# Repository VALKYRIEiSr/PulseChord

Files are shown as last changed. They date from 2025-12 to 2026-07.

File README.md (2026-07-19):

# PulseChord: Wearable Haptic/Vibrational Audio System
**OSHWA Certified Open Source Hardware | PK000001**
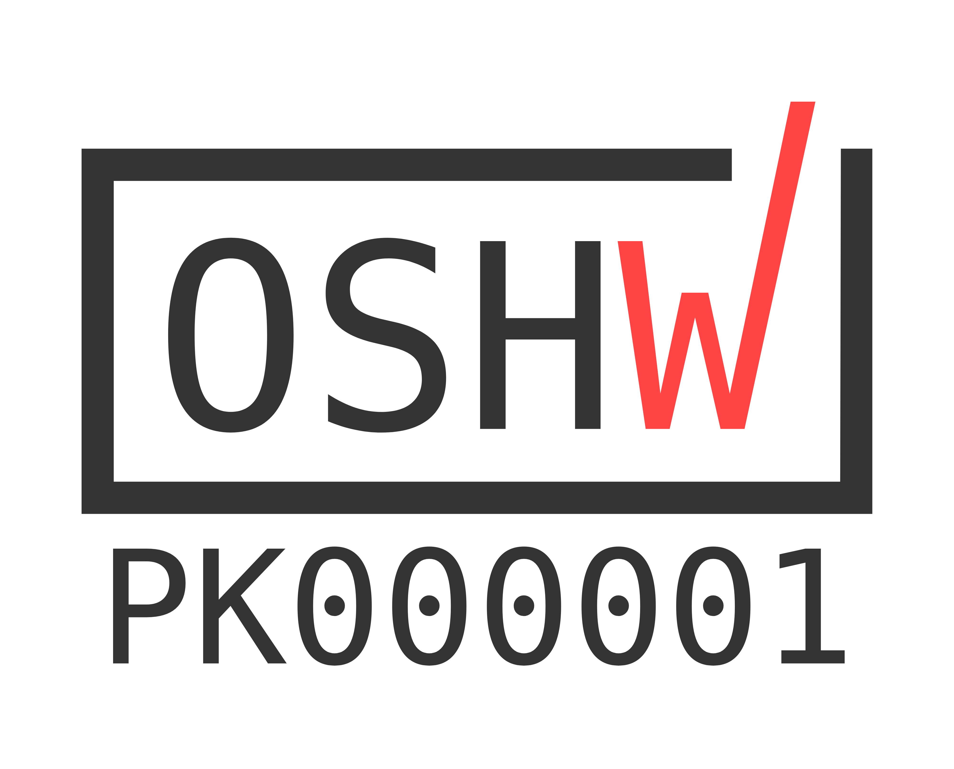
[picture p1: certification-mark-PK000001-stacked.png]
OSHWA Certification

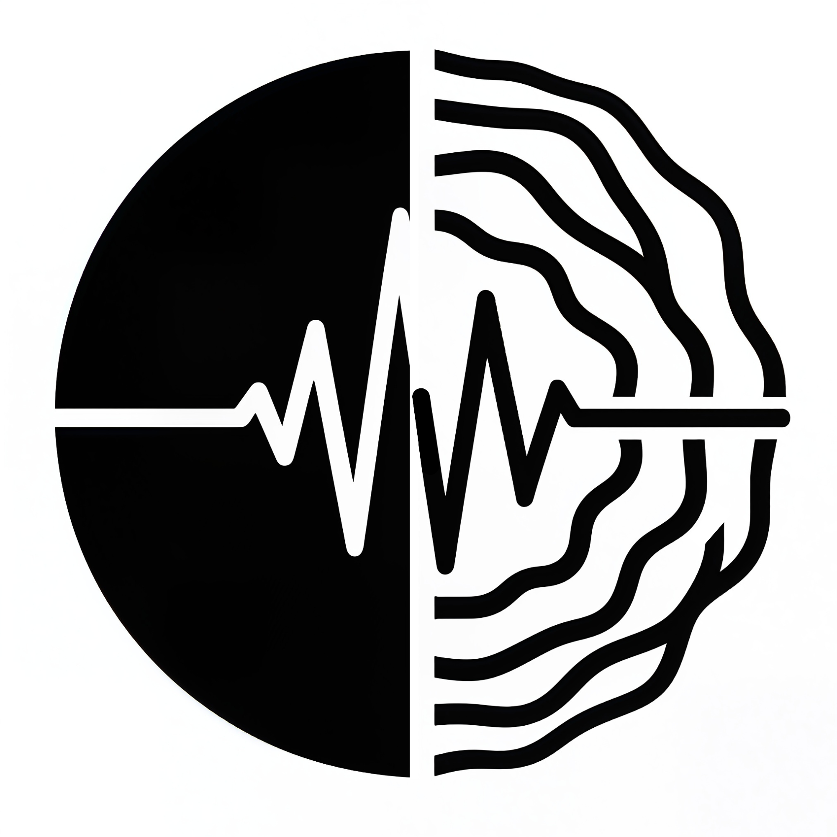
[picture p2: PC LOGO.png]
PulseChord Logo


## Project Overview
PulseChord is a purely analog haptic feedback belt that converts live audio into tactile vibrations through voice coil actuators positioned around the torso/waist. Designed to create an immersive sensory experience, it delivers real-time feedback corresponding to musical rhythm and dynamics.

This project bridges the gap between digital audio and physical sensation, utilizing an industrial manufacturing substrate to create an accessible, wearable haptic interface.

## Press & Recognition
PulseChord was featured as Pakistan's first OSHWA-certified project in the January 2026 Open Source Hardware Certification roundup:
* **Make: Magazine** — [Open Source Hardware Certifications for January 2026](https://makezine.com/article/technology/open-source/open-source-hardware-certifications-for-january-2026/)
* **Hackster.io** — [January 2026 Open Source Hardware Certification Roundup](https://www.hackster.io/news/january-2026-open-source-hardware-certification-roundup-2705cc24ead9)

## Technical Research
The academic theory and signal-conditioning research behind this project can be found on SSRN:
* **SSRN Research Paper:** [PulseChord: Wearable Haptic Systems](https://papers.ssrn.com/sol3/papers.cfm?abstract_id=5532803) (Please refer to for more details)

## Technical Specifications
* **Architecture:** Purely Analog Signal Processing (No Software/Microcontroller)
* **Haptic Drivers:** 6x Full-range vibrational voice coil actuators (4Ω, 5W)
* **Amplification:** Dual TPA3110 (XHA232) Class D Stereo Amplifiers
* **Wiring Configuration:** Drivers are wired in **series pairs** (8Ω per pair) as shown in `Schematic 2.png`.
* **Conditioning:** TL074-based low-noise quad op-amp stage
* **Power:** 11.1V 3S LiPo Battery (2200mAh)
* **Chassis:** 50mm High-durability Nylon webbing with 3D-printed modular mounts
* **Fasteners:** M2 x 30mm Stainless Steel hardware

## Repository Structure
* `Hardware`: Eagle Schematic (`.sch`) and Board (`.brd`) files
* `Mechanical`: 3D source files (`.stl`, `.FCStd`) for speaker holders
* `BOM.txt`: Formatted Bill of Materials with manufacturer specifications
* `BOM.xlxs`: Formatted Bill of Materials with costs
* `LICENSE.txt`: Hardware (CERN-OHL-P-2.0) and Documentation (CC-BY-SA-4.0) licenses
* `GerberFiles.zip`: Production-ready files for PCB fabrication

## Assembly Quick-Start
1. **PCB:** Fabricate the Gerber files using a standard 2-layer FR4 process.
2. **Printing:** Print 6x `Holder Design-Body.stl` in PLA (20% infill).
3. **Mechanical Assembly:** First, mount the speakers into the 3D-printed holders using M2 x 30mm screws and nuts, as detailed in **Speaker.png**.
    * Once secured, thread the 50mm nylon strap through the integrated slots in the holders.
    * Finally, glue, staple, or stitch the velcro hook to one end and the velco loop to the other.
4. **Wiring:** Wire the speakers in series pairs as detailed in **Schematic 2.png**. Connect each 8Ω load to the amplifier output channels.

## Licensing
* **Hardware:** [CERN-OHL-P-2.0](https://spdx.org/licenses/CERN-OHL-P-2.0.html)
* **Documentation:** [CC-BY-SA-4.0](https://creativecommons.org/licenses/by-sa/4.0/)

---
**Developer:** Hariz Zoran Farooq
**Contact:** harizzoranfarooq@gmail.com
*Certified with the Open Source Hardware Association | PK000001.*

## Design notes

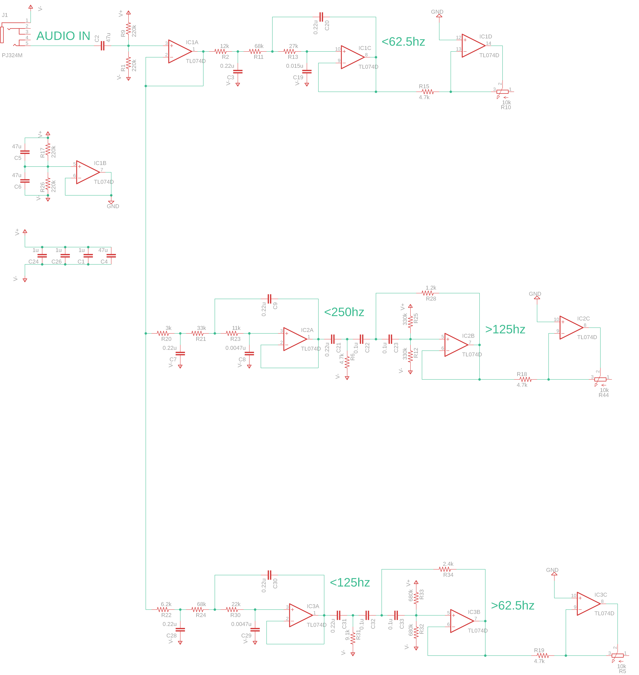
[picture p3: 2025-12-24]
Schematic.png

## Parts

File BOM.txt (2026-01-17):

================================================================================
                       BILL OF MATERIALS: PULSECHORD
================================================================================
Project Status: OSHWA-Compliant Documentation
License:        CERN-OHL-P (Hardware), CC-BY-SA (Documentation)

1. SURFACE MOUNT DEVICES (PCB COMPONENTS)
--------------------------------------------------------------------------------
PART            VALUE       PACKAGE         DESCRIPTION
--------------------------------------------------------------------------------
C1, C24, C26    1u          C0603           Ceramic Capacitor
C2, C4-C6       47u         C0603           Ceramic Capacitor (Bulk)
C3, C7, C9      0.22u       C0603           Ceramic Capacitor
C20, C21        0.22u       C0603           Ceramic Capacitor
C28, C30, C31   0.22u       C0603           Ceramic Capacitor
C8, C29         0.0047u     C0603           Ceramic Capacitor
C19             0.015u      C0603           Ceramic Capacitor
C22, C23        0.1u        C0603           Ceramic Capacitor (Bypass)
C32, C33        0.1u        C0603           Ceramic Capacitor (Bypass)
IC1-IC3         TL074C      SO14            Low-Noise Quad Op-Amp
J1              PJ324M      PJ324M          3.5mm Stereo Audio Jack
R1, R9, R17     220k        R0603           Resistor
R26             220k        R0603           Resistor
R2              12k         R0603           Resistor
R5, R10, R44    10k         3RP/1610N       Potentiometer (Linear)
R6, R15, R18    4.7k        R0603           Resistor
R19             4.7k        R0603           Resistor
R11, R24        68k         R0603           Resistor
R12, R25        330k        R0603           Resistor
R13             27k         R0603           Resistor
R20             3k          R0603           Resistor
R21             33k         R0603           Resistor
R22             6.2k        R0603           Resistor
R23             11k         R0603           Resistor
R28             1.2k        R0603           Resistor
R30             22k         R0603           Resistor
R31             9.1k        R0603           Resistor
R32, R33        680k        R0603           Resistor
R34             2.4k        R0603           Resistor

2. AUDIO & POWER ELECTRONICS
--------------------------------------------------------------------------------
ITEM                    SPECIFICATION           QTY     NOTES
--------------------------------------------------------------------------------
Printed Circuit Board   49.1mm x 54.9mm         1       PulseChord.sch
Stereo Amplifier        TPA3110 (XHA232)        2       30W + 30W Class D
Full Range Speaker      4 Ohm, 5W               6       40mm Driver
LiPo Battery            2200mAh, 11.1V          1       3-Cell (3S) Pack

3. MECHANICALS, TEXTILES & 3D ASSETS
--------------------------------------------------------------------------------
ITEM                    SPECIFICATION           QTY     SOURCE / NOTES
--------------------------------------------------------------------------------
Speaker Holder          3D Printed (PLA)        6       Holder Design-Body.stl
Fastener: Screw         M2 x 30mm               24      Socket Head Cap
Fastener: Nut           M2 Hex Nut              24      Standard M2 Metric
Main Strap              Nylon Webbing (50mm w)  122cm   Flat black (approx 4ft)
Strap Fastener          Loop (Velcro)           20cm    Sewn to strap end
Strap Fastener          Hook (Velcro)           5cm     Sewn to strap end

--------------------------------------------------------------------------------

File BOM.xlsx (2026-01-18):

Item / Material | Quantity | Price (PKR) | Total (PKR) | Source
1. SURFACE MOUNT DEVICES (PCB COMPONENTS)
C1, C24, C26 (1u C0603 Ceramic Capacitor) | 3 | 16 | 48 | https://www.evselectro.com/capacitors/smd-capacitors-0603
C2, C4-C6 (47u C0603 Ceramic Capacitor) | 4 | 9 | 36 | https://www.evselectro.com/capacitors/smd-capacitors-0603
C3, C7, C9 (0.22u C0603 Ceramic Capacitor) | 3 | 7 | 21 | https://www.evselectro.com/capacitors/smd-capacitors-0603
C20, C21 (0.22u C0603 Ceramic Capacitor) | 2 | 7 | 14 | https://www.evselectro.com/capacitors/smd-capacitors-0603
C28, C30, C31 (0.22u C0603 Ceramic Capacitor) | 3 | 7 | 21 | https://www.evselectro.com/capacitors/smd-capacitors-0603
C8, C29 (0.0047u C0603 Ceramic Capacitor) | 2 | 7 | 14 | https://www.evselectro.com/capacitors/smd-capacitors-0603
C19 (0.015u C0603 Ceramic Capacitor) | 1 | 7 | 7 | https://www.evselectro.com/capacitors/smd-capacitors-0603
C22, C23 (0.1u C0603 Ceramic Capacitor) | 2 | 7 | 14 | https://www.evselectro.com/capacitors/smd-capacitors-0603
C32, C33 (0.1u C0603 Ceramic Capacitor) | 2 | 7 | 14 | https://www.evselectro.com/capacitors/smd-capacitors-0603
IC1-IC3 (TL074C SO14 Low-Noise Quad Op-Amp) | 3 | 70 | 210 | https://digilog.pk/products/tl074c-smd-in-pakistan?_pos=2&_psq=TL0&_ss=e&_v=1.0
J1 (PJ324M PJ324M 3.5mm Stereo Audio Jack) | 1 | 20 | 20 | https://digilog.pk/products/pcb-mount-female-audio-connector-dip-stereo-headphone-jack-in-pakistan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
R1, R9, R17 (220k R0603 Resistor 1% 0.1W) | 3 | 6 | 18 | https://www.evselectro.com/resistors/smd-resistors-0603-1
R26 (220k R0603 Resistor 1% 0.1W) | 1 | 6 | 6 | https://www.evselectro.com/resistors/smd-resistors-0603-1
R2 (12k R0603 Resistor 1% 0.1W) | 1 | 6 | 6 | https://www.evselectro.com/resistors/smd-resistors-0603-1
R5, R10, R44 (10k 3RP/1610N Potentiometer - Linear) | 3 | 30 | 90 | https://digilog.pk/products/variable-resistor-potentiometer-volume-type?_pos=1&_sid=8f88ca3c8&_ss=r
R6, R15, R18 (4.7k R0603 Resistor 1% 0.1W) | 3 | 6 | 18 | https://www.evselectro.com/resistors/smd-resistors-0603-1
R19 (4.7k R0603 Resistor 1% 0.1W) | 1 | 6 | 6 | https://www.evselectro.com/resistors/smd-resistors-0603-1
R11, R24 (68k R0603 Resistor 1% 0.1W) | 2 | 6 | 12 | https://www.evselectro.com/resistors/smd-resistors-0603-1
R12, R25 (330k R0603 Resistor 1% 0.1W) | 2 | 6 | 12 | https://www.evselectro.com/resistors/smd-resistors-0603-1
R13 (27k R0603 Resistor 1% 0.1W) | 1 | 6 | 6 | https://www.evselectro.com/resistors/smd-resistors-0603-1
R20 (3k R0603 Resistor 1% 0.1W) | 1 | 6 | 6 | https://www.evselectro.com/resistors/smd-resistors-0603-1
R21 (33k R0603 Resistor 1% 0.1W) | 1 | 6 | 6 | https://www.evselectro.com/resistors/smd-resistors-0603-1
R22 (6.2k R0603 Resistor 1% 0.1W) | 1 | 6 | 6 | https://www.evselectro.com/resistors/smd-resistors-0603-1
R23 (11k R0603 Resistor 1% 0.1W) | 1 | 6 | 6 | https://www.evselectro.com/resistors/smd-resistors-0603-1
R28 (1.2k R0603 Resistor 1% 0.1W) | 1 | 6 | 6 | https://www.evselectro.com/resistors/smd-resistors-0603-1
R30 (22k R0603 Resistor 1% 0.1W) | 1 | 6 | 6 | https://www.evselectro.com/resistors/smd-resistors-0603-1
R31 (9.1k R0603 Resistor 1% 0.1W) | 1 | 6 | 6 | https://www.evselectro.com/resistors/smd-resistors-0603-1
R32, R33 (680k R0603 Resistor 1% 0.1W) | 2 | 6 | 12 | https://www.evselectro.com/resistors/smd-resistors-0603-1
R34 (2.4k R0603 Resistor 1% 0.1W) | 1 | 6 | 6 | https://www.evselectro.com/resistors/smd-resistors-0603-1
2. AUDIO & POWER ELECTRONICS |  |  | 0
Stereo Amplifier TPA3110 (XHA232) | 2 | 600 | 1200 | https://digilog.pk/products/2-channel-digital-stereo-audio-power-amplifier-board-xha232-in-pakistan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
Full Range Speaker 4 Ohm, 5W (40mm Driver) | 6 | 140 | 840 | https://digilog.pk/products/4-ohm-5-watt-speaker-in-pakistan?_pos=2&_psq=speaker&_ss=e&_v=1.0
LiPo Battery 2200mAh, 11.1V (3S Pack) | 1 | 5000 | 5000 | https://electrobes.com/product/2200mah-11-1v-3s-30c-lipo-lithium-polymer-rechargeable-battery-pack-for-rc-drone/
PCB(Bulk Cost) (49.1mm x 54.9mm) | 1 | 100 | 100 | https://itelectrotech.com
3. MECHANICALS, TEXTILES & 3D ASSETS
Speaker Holder 3D Printed (PLA) | 36.954 | 15 | 554.31 | Local Hardware
Fastener: Screw M2 x 30mm (Socket Head Cap) | 24 | 3 | 72 | Local Hardware
Fastener: Nut M2 Hex Nut (Standard M2 Metric) | 24 | 1 | 24 | Local Hardware
Main Strap Nylon Webbing (50mm w) | 122 | 1 | 122 | https://s.daraz.pk/s.1X0Yb
Strap Fastener Loop (Velcro) | 20 | 0.4166666667 | 8.333333333 | https://s.daraz.pk/s.1X00a
Strap Fastener Hook (Velcro) | 5 | 0.4166666667 | 2.083333333 | https://s.daraz.pk/s.1X00a
 |  |  | 8575.726667 | Note: 3D-printed components are measured in grams, while the nylon strap and velcro are measured in centimeters. All costs and exchange rates reflect market values at the time of documentation and are subject to change.
 |  |  | 30.6153442 USD

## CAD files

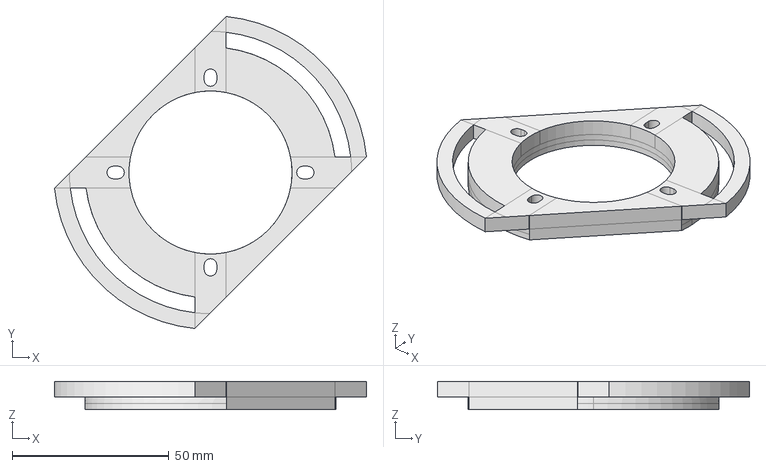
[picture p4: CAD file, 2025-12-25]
Holder Design.FCStd
99.5 x 99.5 x 9.00 mm

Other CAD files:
Holder Design-Body.stl

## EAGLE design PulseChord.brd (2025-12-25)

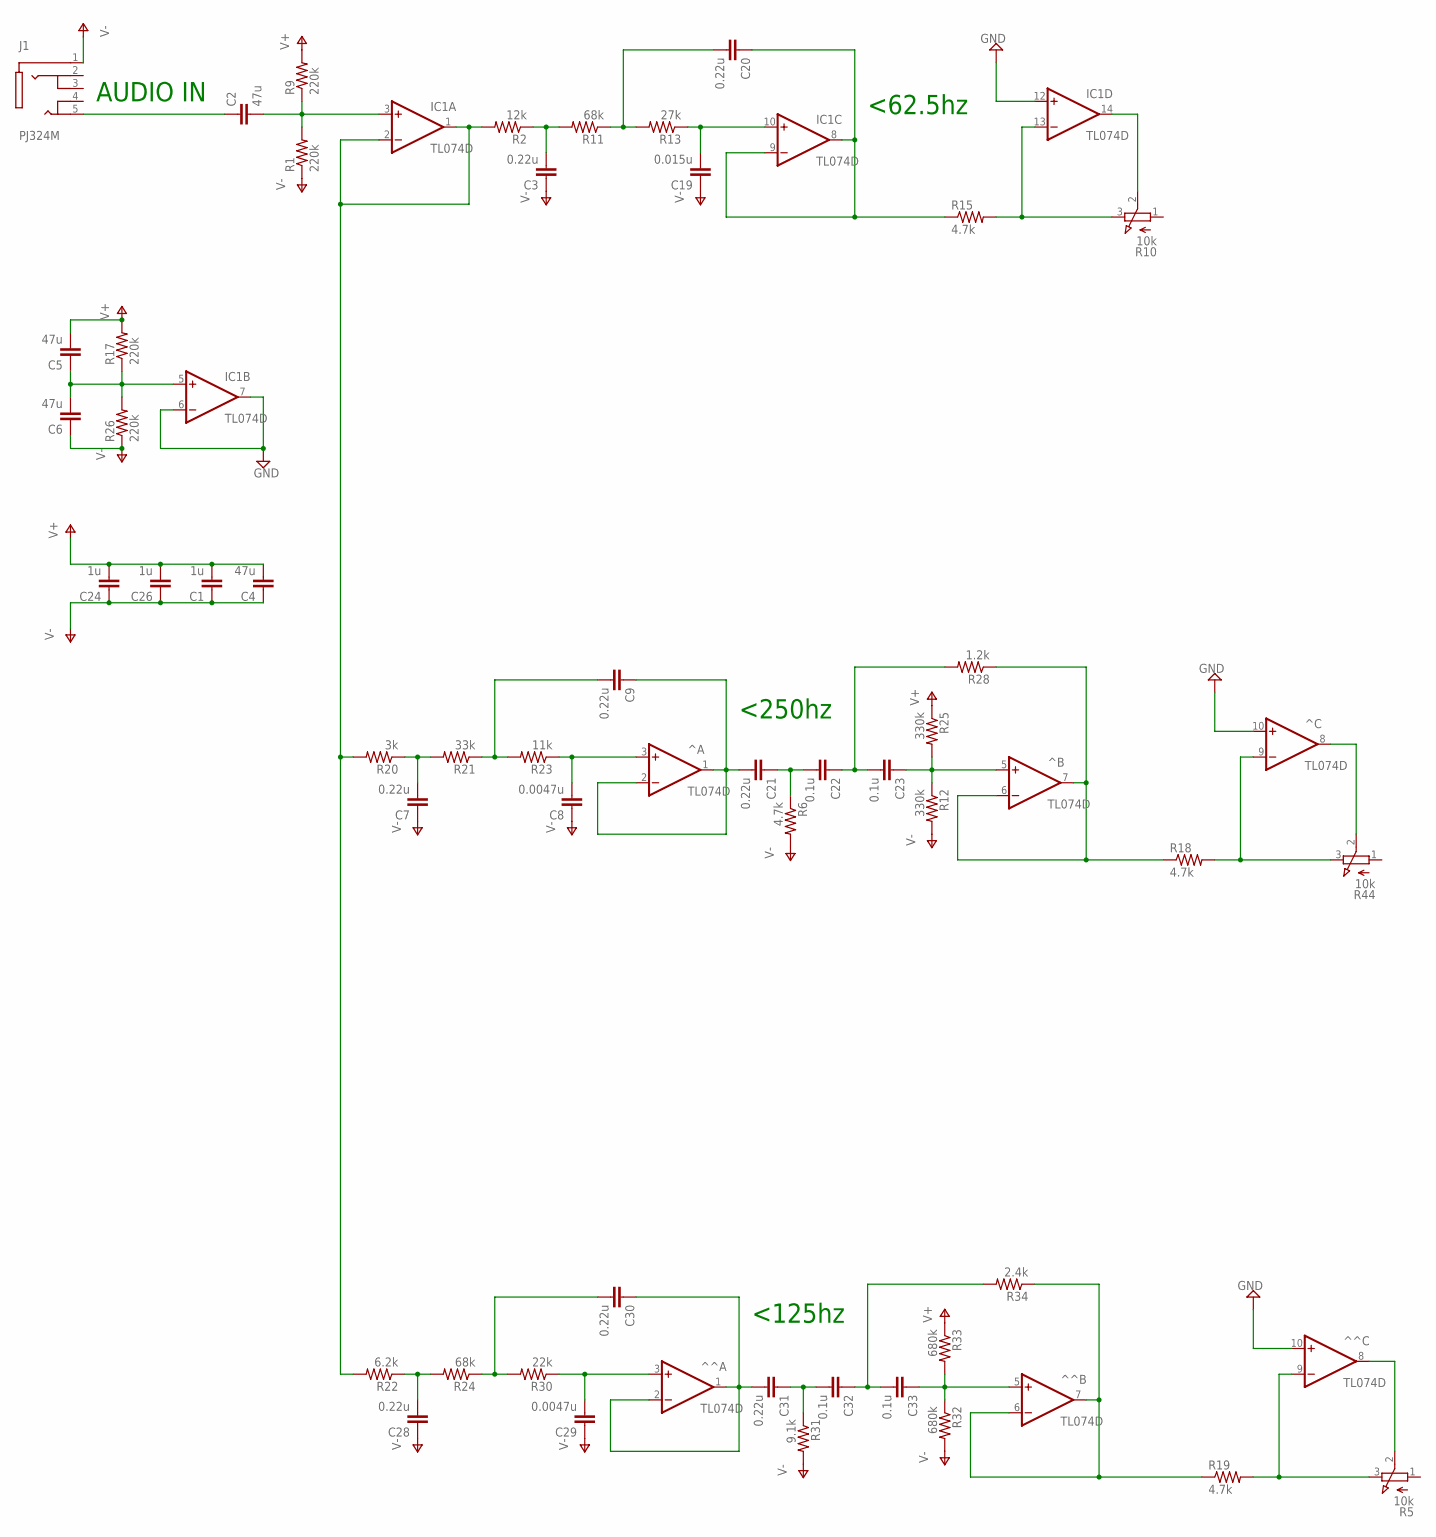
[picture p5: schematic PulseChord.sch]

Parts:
C1, C24, C26: 1u; C0603
C2, C4, C5, C6: 47u; C0603
C3, C7, C9, C20, C21, C28, C30, C31: 0.22u; C0603
C8, C29: 0.0047u; C0603
C19: 0.015u; C0603
C22, C23, C32, C33: 0.1u; C0603
IC1: TL074D; SO14
J1: PJ324M; WENZHOU_PJ324M
R1, R9, R17, R26: 220k; R0603
R2: 12k; R0603
R5, R10, R44: 10k; 3RP/1610N
R6, R15, R18, R19: 4.7k; R0603
R11, R24: 68k; R0603
R12, R25: 330k; R0603
R13: 27k; R0603
R20: 3k; R0603
R21: 33k; R0603
R22: 6.2k; R0603
R23: 11k; R0603
R28: 1.2k; R0603
R30: 22k; R0603
R31: 9.1k; R0603
R32, R33: 680k; R0603
R34: 2.4k; R0603
^: TL074D; SO14
^^: TL074D; SO14

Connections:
GND: IC1.6 (-IN), IC1.7 (OUT), IC1.12 (+IN), ^.10 (+IN), ^^.10 (+IN)
unnamed: IC1.1 (OUT), IC1.2 (-IN), R2.2, R20.2, R22.2
unnamed: C2.2, IC1.3 (+IN), R1.2, R9.1
unnamed: R5.3 (E), R19.2, ^^.9 (-IN)
unnamed: R5.2 (S), ^^.8 (OUT)
unnamed: C5.1, C6.2, IC1.5 (+IN), R17.1, R26.2
unnamed: C8.2, R23.1, ^.3 (+IN)
unnamed: IC1.13 (-IN), R10.3 (E), R15.2
unnamed: C9.2, R21.1, R23.2
unnamed: C3.2, R2.1, R11.2
unnamed: C2.1, J1.5 (TIP_2)
unnamed: C21.1, C22.2, R6.1
unnamed: C9.1, C21.2, ^.1 (OUT), ^.2 (-IN)
unnamed: C31.1, C32.2, R31.1
unnamed: C19.2, IC1.10 (+IN), R13.1
unnamed: C30.1, C31.2, ^^.1 (OUT), ^^.2 (-IN)
unnamed: C32.1, C33.2, R34.2
unnamed: C22.1, C23.2, R28.2
unnamed: C33.1, R32.1, R33.2, ^^.5 (+IN)
unnamed: C7.2, R20.1, R21.2
unnamed: R19.1, R34.1, ^^.6 (-IN), ^^.7 (OUT)
unnamed: C28.2, R22.1, R24.2
unnamed: IC1.14 (OUT), R10.2 (S)
unnamed: C20.2, R11.1, R13.2
unnamed: R18.2, R44.3 (E), ^.9 (-IN)
unnamed: C23.1, R12.1, R25.2, ^.5 (+IN)
unnamed: R44.2 (S), ^.8 (OUT)
unnamed: C30.2, R24.1, R30.2
unnamed: R18.1, R28.1, ^.6 (-IN), ^.7 (OUT)
unnamed: C20.1, IC1.8 (OUT), IC1.9 (-IN), R15.1
unnamed: C29.2, R30.1, ^^.3 (+IN)
V+: C1.2, C4.2, C5.2, C24.2, C26.2, IC1.4 (V+), R9.2, R17.2, R25.1, R33.1, ^.4 (V+), ^^.4 (V+)
V-: C1.1, C3.1, C4.1, C6.1, C7.1, C8.1, C19.1, C24.1, C26.1, C28.1, C29.1, IC1.11 (V-), J1.1 (SLEEVE), R1.1, R6.2, R12.2, R26.1, R31.2, R32.2, ^.11 (V-), ^^.11 (V-)

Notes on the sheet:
<250hz
<125hz
AUDIO IN
<62.5hz

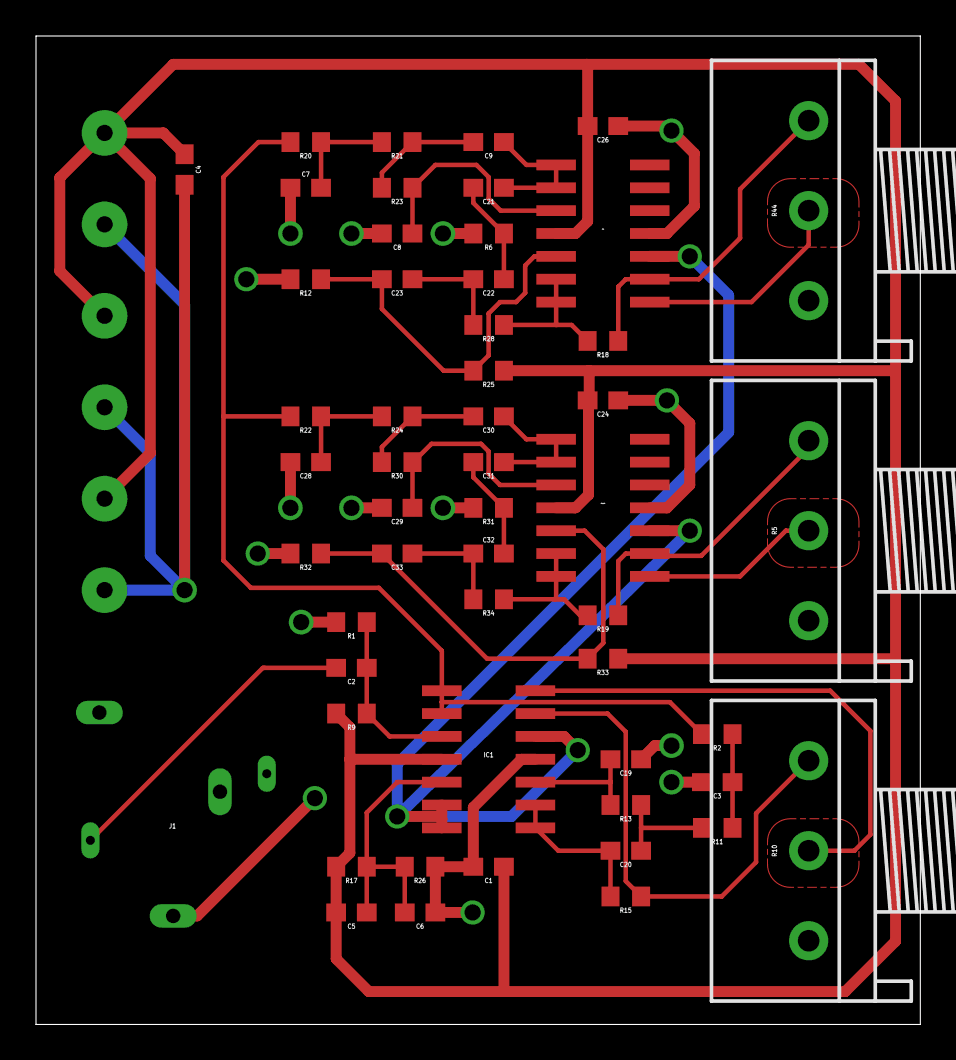
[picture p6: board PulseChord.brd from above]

Board: 2 copper layers, 49.1 x 54.9 mm, 53 parts (1 on the bottom side), 33 nets.
